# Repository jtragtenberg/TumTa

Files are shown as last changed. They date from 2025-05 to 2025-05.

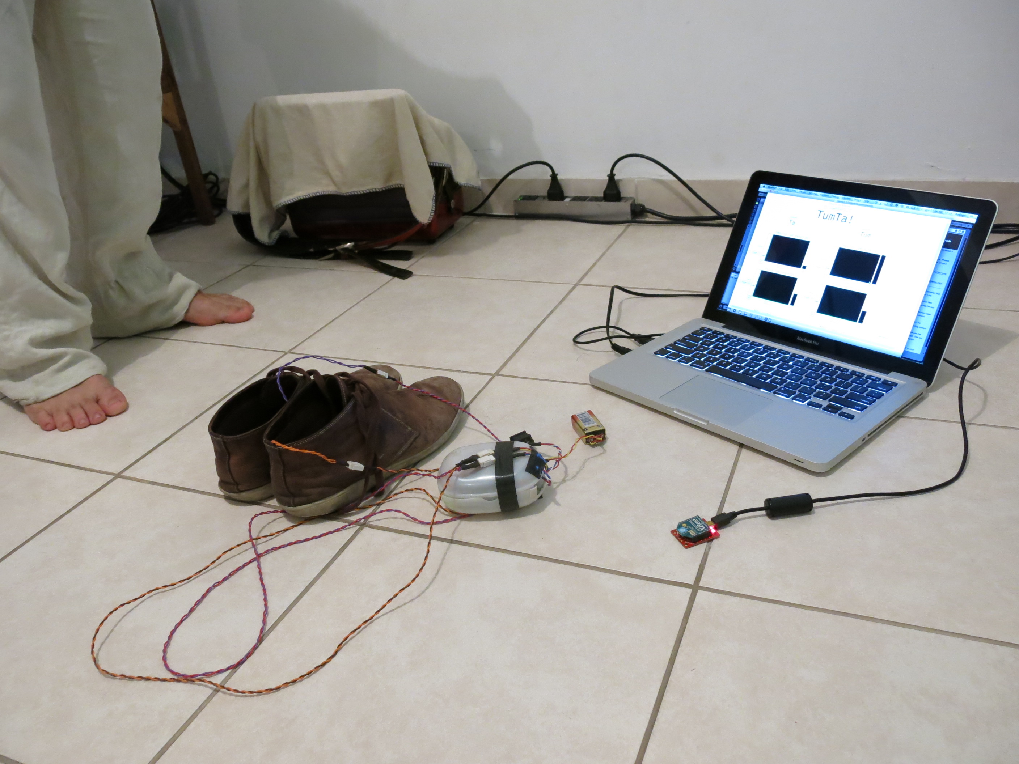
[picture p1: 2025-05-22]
Imagens/IMG_2408.JPG

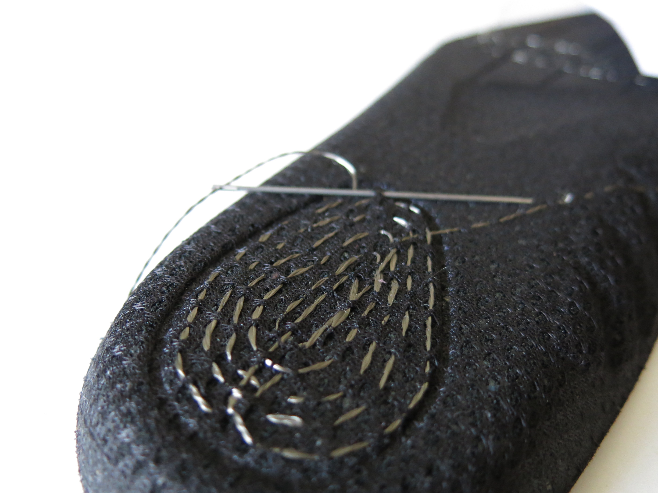
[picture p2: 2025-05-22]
Imagens/IMG_2268.JPG

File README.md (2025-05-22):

# TumTa - Instrumento Digital de Dança e Música voltado a disparar samples sonoros a partir de pisadas através de uma palmilha sensível à pressão (FSR).

## Descrição

**TumTa** é um sistema híbrido, modular e open-source, que integra:

- Hardware de detecção percussiva sensível ao toque.
- Firmware embarcado com processamento em tempo real.
- Comunicação sem fio via **XBee**.
- Software receptor/visualizador desenvolvido em **C++ com OpenFrameworks**.

O sistema foi desenvolvido para aplicações em:

- Performance musical ao vivo.
- Instalações audiovisuais interativas.
- Pesquisas em interfaces físico-digitais.

## Componentes do Projeto

### 1. Circuito eletrônico

- Projeto de circuito com sensores piezoelétricos.
- Arquivos disponíveis no repositório:
  - Esquema elétrico (.sch).
  - PCB para fabricação ou CNC (.brd).
  - Layout da caixa para **corte a laser** (.svg ou .dxf).

Todos os arquivos estão na pasta `hardware/`.

### 2. Firmware (Arduino)

- Processamento de sinais em tempo real com:
  - Derivada via diferenças finitas (float).
  - Controle **não bloqueante** com `millis()`.
  - Sistema de **debounce** ajustável.
  - Modos de envio: `DEBUG` e `LIVE`.

- Comunicação serial com módulo **XBee** para transmissão sem fio.
- Código modular e otimizado disponível na pasta `firmware/`.

### 3. Comunicação sem fio (XBee)

- Configuração clássica:
  - Transmissor: Arduino + XBee.
  - Receptor: XBee + computador.

- Baudrate: 38400.
- Comunicação robusta com protocolo de mensagem e **checksum**.

### 4. Software receptor (OpenFrameworks)

Desenvolvido em **C++ com OpenFrameworks**, o software realiza:

- Recepção e interpretação das mensagens enviadas via XBee.
- Detecção de picos ajustável, permitindo o controle da sensibilidade à intensidade.
- Mapeamento dinâmico: a intensidade controla diretamente a dinâmica dos samples gerados.
- Contorno de ruídos: filtros e thresholds ajustáveis para minimizar falsos disparos.
- Interface com `ofxGui` para ajuste em tempo real.
- Visualização gráfica dos dados recebidos.

**Integração MIDI**:

- O software converte os eventos de detecção percussiva em **mensagens MIDI**.
- Utiliza bibliotecas como `ofxMidi` para envio MIDI.
- As mensagens MIDI são enviadas em tempo real para uma **DAW** (ex.: **Ableton Live**, **Logic Pro**, **Reaper**).
- Cada batida detectada pode ser mapeada para **notas MIDI específicas**, disparando samples ou instrumentos virtuais.

## Fluxo geral do sistema

```
Sensor Piezo → Arduino → Processamento → XBee TX → ~~~ Wireless ~~~ → XBee RX → OpenFrameworks → MIDI OUT → DAW (Ableton Live)
```

## Arquivos incluídos no repositório

| Pasta | Conteúdo |
|---|---|
| `PCB/ Enclosure/ | Esquema, PCB (.brd/.sch), layout da caixa (.svg/.dxf). |
| `Arduino/` | Código Arduino (`TumTa.ino`). |
| `OpenFrameWorks/`| Projeto OpenFrameworks com envio MIDI. |
| `Imagens/` | Fotos |
| `Max/` | Software Aternativo |

## Como montar o sistema

### 1. Hardware

- Construa o circuito com base no esquema elétrico.
- Corte a caixa com laser utilizando os arquivos vetoriais.
- Monte os componentes, conecte sensores, potenciômetro e switches.

### 2. Firmware

- Abra o `TumTa.ino` no Arduino IDE.
- Compile e envie para a placa Arduino.

### 3. Comunicação

- Configure os módulos **XBee**:
  - Mesma PAN ID.
  - Baudrate: 38400.
- Conecte o transmissor ao Arduino e o receptor ao computador.

### 4. Software

- Instale **OpenFrameworks** (versão 0.11 ou superior).
- Inclua `ofxMidi` para envio de mensagens MIDI.
- Abra o projeto `TumTa` na pasta `software/`.
- Ajuste:
  - Porta serial para XBee receptor.
  - Configurações MIDI (porta virtual ou física).
- Compile e execute.
- Configure a DAW (ex.: **Ableton Live**) para receber as mensagens MIDI provenientes do software.

## Parâmetros ajustáveis

| Parâmetro | Local | Valor padrão |
|--- |--- |--- |
| Threshold | Potenciômetro (A7) | Variável |
| Debounce Time | Estrutura `ChannelState` | 150 ms |
| Process Interval | Global | 1 ms |
| Tempo de Pisca (LED) | Global | 500 ms |
| Sensibilidade de Pico | Interface do OpenFrameworks | Ajustável |
| Dinâmica de Sample/MIDI  | Mapeamento no software | Ajustável |
| Notas MIDI mapeadas | Configuração no OpenFrameworks | Ajustável |

## Diferenciais do projeto

- Modular e expansível, com suporte para múltiplos sensores.
- Processamento híbrido, com divisão de carga entre hardware e software.
- Integração robusta com sistemas artísticos interativos e musicais.
- Arquivos completos: circuito, caixa e software.
- Envio de MIDI para **DAW** em tempo real.

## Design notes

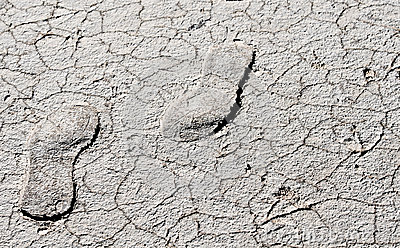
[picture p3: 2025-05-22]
Enclosure/texturas/pegadas-em-uma-terra-rachada-seca-25556899.jpg

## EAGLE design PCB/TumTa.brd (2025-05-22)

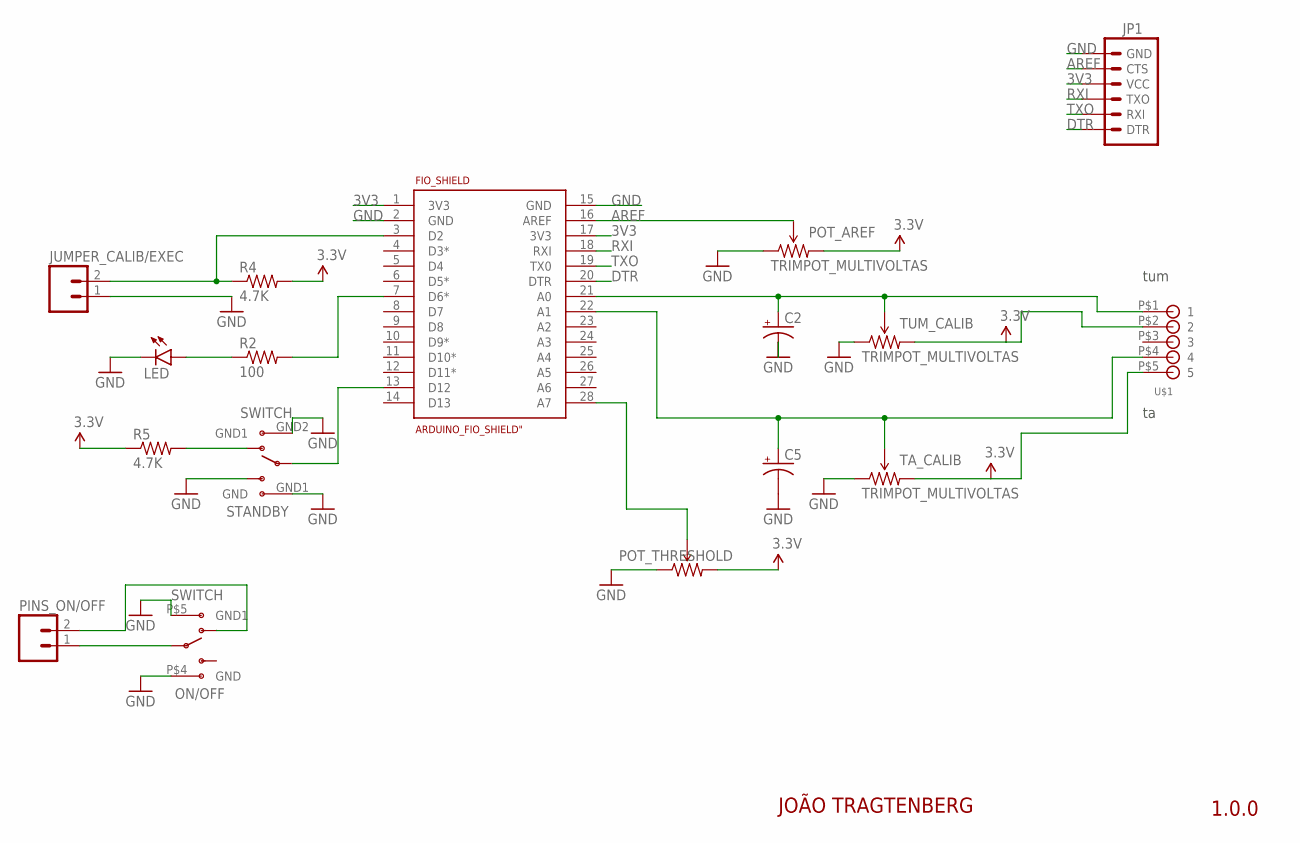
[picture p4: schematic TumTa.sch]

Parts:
C2, C5: CAP_POLPTH2; CPOL-RADIAL-10UF-25V
FIO_SHIELD: ARDUINO_FIO_SHIELD"; ARDUINO_FIO_SHIELD
JP1: ARDUINO_SERIAL_PROGRAMPTH; 1X06
JUMPER_CALIB/EXEC: M02PTH; 1X02
LED: LED-GREEN5MM_THRU; LED5MM
ON/OFF: SWITCH; SWITCH_HH_2POS_3PIN
PINS_ON/OFF: M02PTH; 1X02
POT_AREF: TRIMPOT_MULTIVOLTAS
POT_THRESHOLD: TRIMPOTBR; TRIM_POT_BR
R2: 100; 0603-RES
R4, R5: 4.7K; 0603-RES
STANDBY: SWITCH; SWITCH_HH_2POS_6PIN
TA_CALIB: TRIMPOT_MULTIVOLTAS
TUM_CALIB: TRIMPOT_MULTIVOLTAS
U$1: SCREWTERMINAL-5; SCREWTERMINAL-0.1"-5_BR

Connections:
3V3: FIO_SHIELD.1 (3V3), FIO_SHIELD.17 (3V3), JP1.4 (VCC), POT_AREF.3 (CW), POT_THRESHOLD.3 (CW), R4.2, R5.1, TA_CALIB.3 (CW), TUM_CALIB.3 (CW), U$1.P$2 (2), U$1.P$5 (5)
A0: C2.1 (+), FIO_SHIELD.21 (A0), TUM_CALIB.2 (WIPER), U$1.P$1 (1)
A1: C5.1 (+), FIO_SHIELD.22 (A1), TA_CALIB.2 (WIPER), U$1.P$4 (4)
AREF: FIO_SHIELD.16 (AREF), JP1.5 (CTS), POT_AREF.2 (WIPER)
D10: FIO_SHIELD.7 (D6*), R2.2
DTR: FIO_SHIELD.20 (DTR), JP1.1 (DTR)
GND: C2.2 (-), C5.2 (-), FIO_SHIELD.2 (GND), FIO_SHIELD.15 (GND), JP1.6 (GND), JUMPER_CALIB/EXEC.1, LED.K (C), ON/OFF.P$4 (GND), ON/OFF.P$5 (GND1), POT_AREF.1 (CCW), POT_THRESHOLD.1 (CCW), STANDBY.GND1 (GND), STANDBY.GND2 (GND1), STANDBY.P3A (S), TA_CALIB.1 (CCW), TUM_CALIB.1 (CCW)
unnamed: FIO_SHIELD.28 (A7), POT_THRESHOLD.2 (WIPER)
unnamed: FIO_SHIELD.3 (D2), JUMPER_CALIB/EXEC.2, R4.1
unnamed: FIO_SHIELD.13 (D12), STANDBY.P2A
unnamed: R5.2, STANDBY.P1A (O)
unnamed: ON/OFF.P$1 (O), PINS_ON/OFF.2
unnamed: LED.A, R2.1
unnamed: ON/OFF.P$2, PINS_ON/OFF.1
RXI: FIO_SHIELD.18 (RXI), JP1.3 (TXO)
TXO: FIO_SHIELD.19 (TX0), JP1.2 (RXI)

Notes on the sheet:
JOÃO TRAGTENBERG
1.0.0
tum

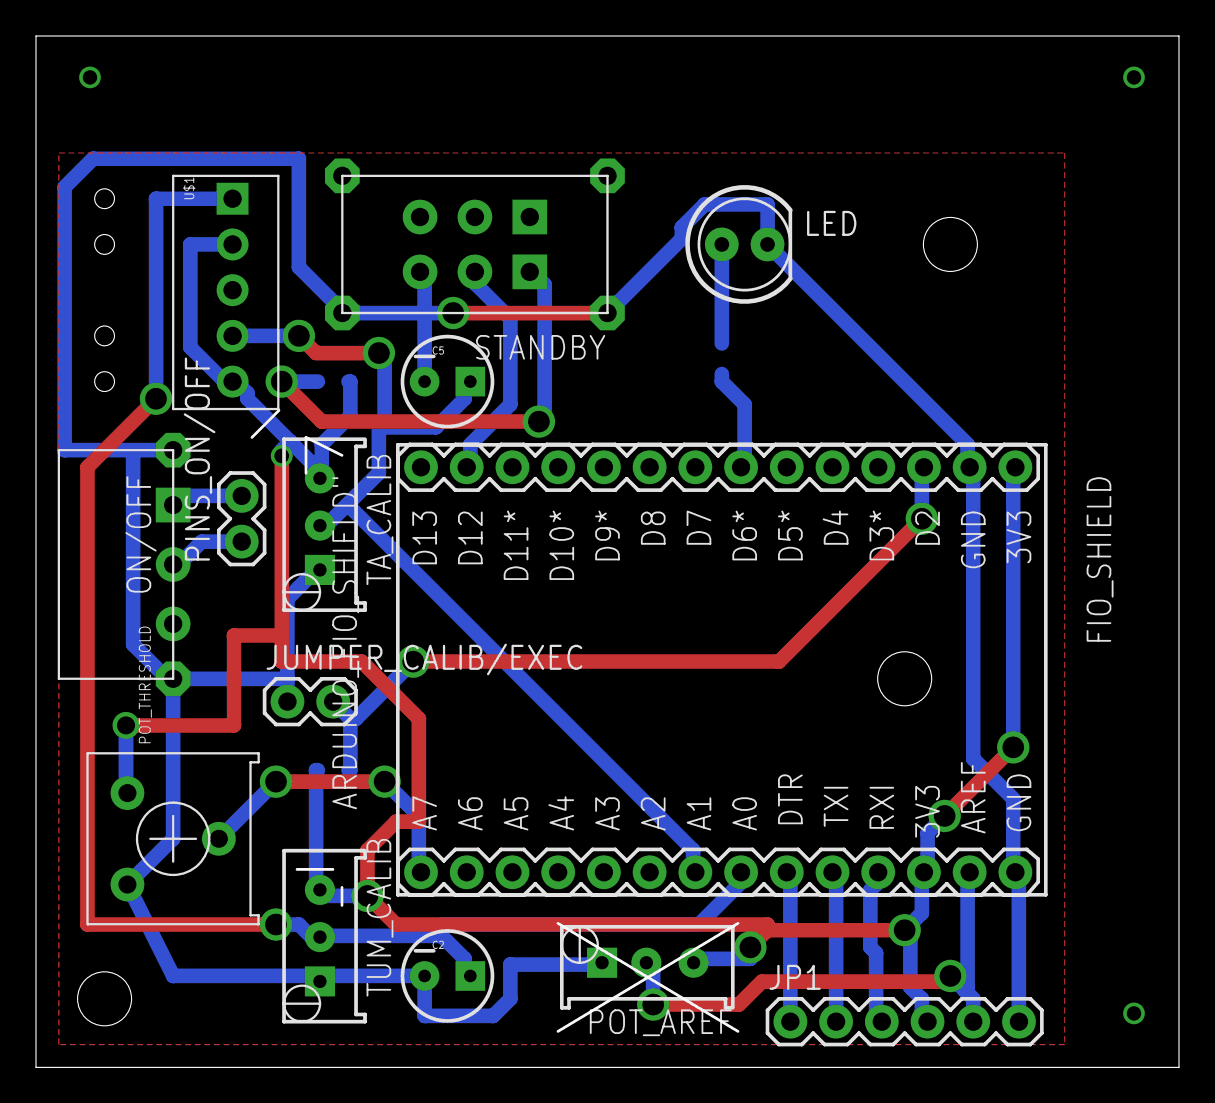
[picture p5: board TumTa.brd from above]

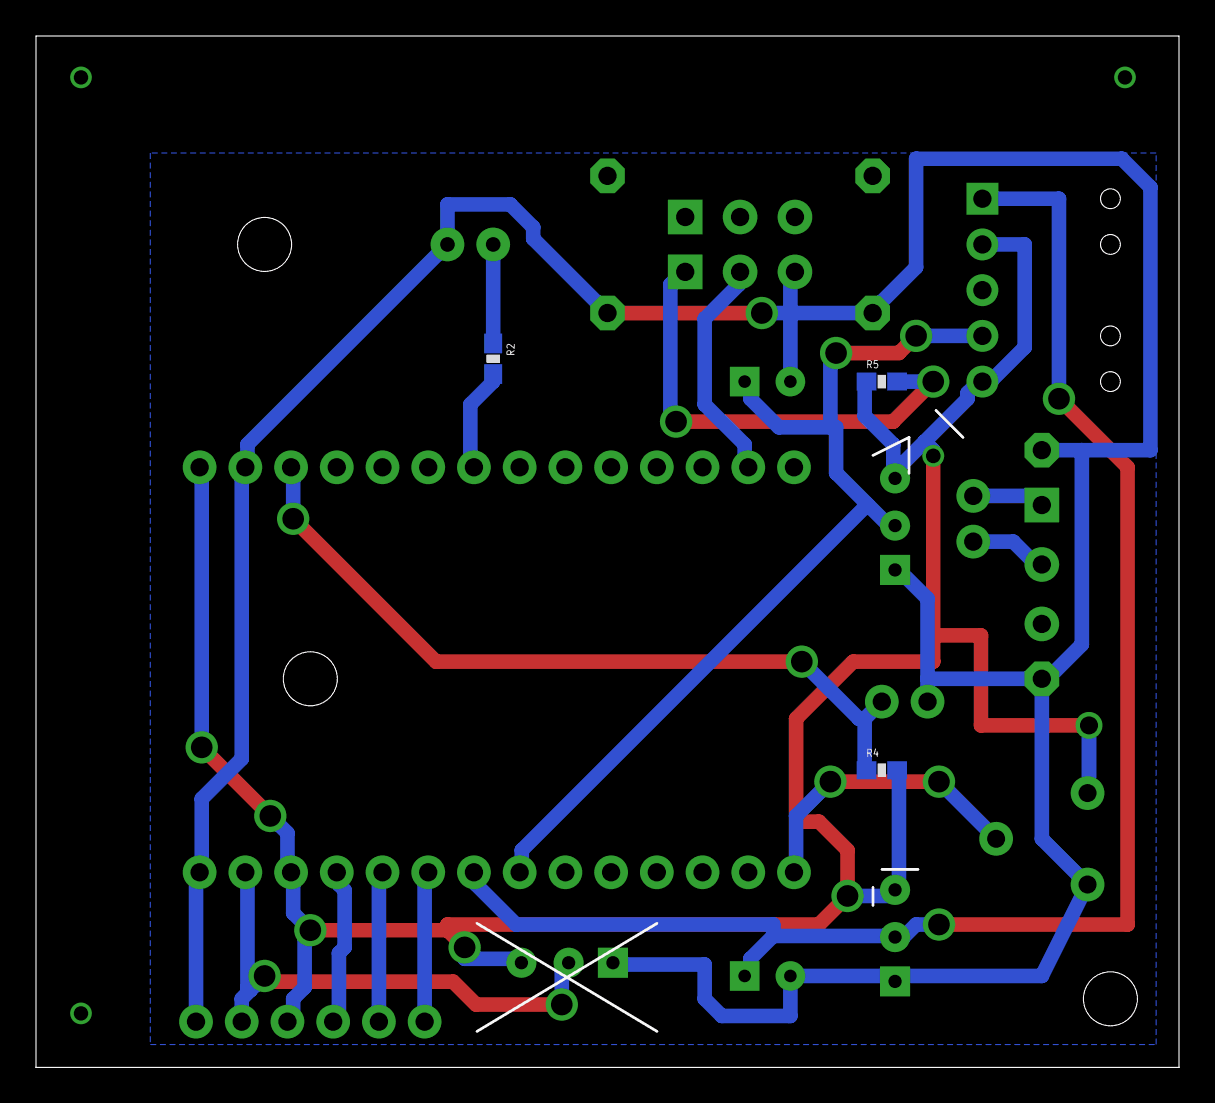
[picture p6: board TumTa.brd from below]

Board: 2 copper layers, 63.5 x 57.3 mm, 17 parts (3 on the bottom side), 16 nets.

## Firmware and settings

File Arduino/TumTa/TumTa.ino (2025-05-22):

// ---- Configurações de pinos ----
#define TUM_PIN A0
#define TUM_CHANNEL 0
#define TA_PIN A1
#define TA_CHANNEL 1
#define MODE_SWITCH_PIN 2
#define THRESHOLD_PIN A7
#define STANDBY_SWITCH_PIN 12
#define LED_PIN 6

// ---- Parâmetros gerais ----
const int numReadings = 5;
int threshold = 20;

const unsigned long processInterval = 1; // intervalo mínimo entre processamentos (ms)
unsigned long lastProcessTime = 0;

typedef struct {
  int debounceTime = 150;
  int derivative = 0;
  int intensity = 0;
  int maxDerivative = 0;
  bool debouncing = false;
  unsigned long lastDebounceTime = 0;
  bool waitingForPeak = true;
  int derivativeWindow[5] = {0};
} ChannelState;

ChannelState channels[2];

// ---- Mensagens ----
byte debugMessage[15];
byte liveMessage[7];

// ---- Variáveis globais ----
bool isDebugging = false;
bool standby = false;
unsigned long tempoStandby = 0;
const int tempoBlink = 500;
bool blinkFlag = false;

// ---- Funções auxiliares ----
float getDerivative(ChannelState *ch, int value) {
  for (int i = 4; i > 0; i--) {
    ch->derivativeWindow[i] = ch->derivativeWindow[i - 1];
  }
  ch->derivativeWindow[0] = value;

  float derivative = 2.08 * ch->derivativeWindow[0] 
                   - 4.0 * ch->derivativeWindow[1] 
                   + 3.0 * ch->derivativeWindow[2] 
                   - 1.33 * ch->derivativeWindow[3] 
                   + 0.25 * ch->derivativeWindow[4];

  return derivative;
}

int computeIntensity(ChannelState *ch, int newDerivative, int threshold) {
  unsigned long now = millis();

  if (!ch->debouncing && newDerivative > threshold) {
    ch->lastDebounceTime = now;
    ch->debouncing = true;
  }

  if ((now - ch->lastDebounceTime) > ch->debounceTime) {
    ch->debouncing = false;
    ch->intensity = 0;
    ch->waitingForPeak = true;
    ch->maxDerivative = 0;
    digitalWrite(LED_PIN, LOW);
  }

  if (ch->debouncing && ch->waitingForPeak) {
    if (newDerivative > ch->maxDerivative) {
      ch->maxDerivative = newDerivative;
    } else {
      ch->intensity = ch->maxDerivative;
      ch->waitingForPeak = false;
      digitalWrite(LED_PIN, HIGH);
      Serial.write(ch->intensity / 10);
    }
  }
  return ch->intensity;
}

void setDebugMessage(int tumPressure, int taPressure, int tumDerivative, int taDerivative, int tumIntensity, int taIntensity) {
  debugMessage[0] = 0xFF;
  debugMessage[1] = 0xFF;
  debugMessage[2] = lowByte(tumPressure);
  debugMessage[3] = highByte(tumPressure);
  debugMessage[4] = lowByte(taPressure);
  debugMessage[5] = highByte(taPressure);
  debugMessage[6] = lowByte(tumDerivative);
  debugMessage[7] = highByte(tumDerivative);
  debugMessage[8] = lowByte(taDerivative);
  debugMessage[9] = highByte(taDerivative);
  debugMessage[10] = lowByte(tumIntensity);
  debugMessage[11] = highByte(tumIntensity);
  debugMessage[12] = lowByte(taIntensity);
  debugMessage[13] = highByte(taIntensity);

  debugMessage[14] = 0;
  for (int i = 2; i < 14; i++) {
    debugMessage[14] += debugMessage[i];
  }

  Serial.write(debugMessage, sizeof(debugMessage));
}

void setLiveMessage(int tumIntensity, int taIntensity) {
  liveMessage[0] = 0xFE;
  liveMessage[1] = 0xFE;
  liveMessage[2] = lowByte(tumIntensity);
  liveMessage[3] = highByte(tumIntensity);
  liveMessage[4] = lowByte(taIntensity);
  liveMessage[5] = highByte(taIntensity);

  liveMessage[6] = 0;
  for (int i = 2; i < 6; i++) {
    liveMessage[6] += liveMessage[i];
  }

  Serial.write(liveMessage, sizeof(liveMessage));
}

// ---- Setup ----
void setup() {
  Serial.begin(38400);

  pinMode(TUM_PIN, INPUT);
  pinMode(TA_PIN, INPUT);
  pinMode(MODE_SWITCH_PIN, INPUT);
  pinMode(THRESHOLD_PIN, INPUT);
  pinMode(STANDBY_SWITCH_PIN, INPUT);
  pinMode(LED_PIN, OUTPUT);
}

// ---- Loop ----
void loop() {
  unsigned long now = millis();

  standby = digitalRead(STANDBY_SWITCH_PIN);
  threshold = analogRead(THRESHOLD_PIN);

  if (standby) {
    if (now - tempoStandby > tempoBlink) {
      digitalWrite(LED_PIN, blinkFlag ? LOW : HIGH);
      tempoStandby = now;
      blinkFlag = !blinkFlag;
    }
  } else {
    if (now - lastProcessTime >= processInterval) {
      lastProcessTime = now;

      isDebugging = digitalRead(MODE_SWITCH_PIN);

      int tumValue = analogRead(TUM_PIN);
      int taValue = analogRead(TA_PIN);

      float tumDerivative = getDerivative(&channels[TUM_CHANNEL], tumValue);
      float taDerivative = getDerivative(&channels[TA_CHANNEL], taValue);

      int tumIntensity = computeIntensity(&channels[TUM_CHANNEL], tumDerivative, threshold);
      int taIntensity = computeIntensity(&channels[TA_CHANNEL], taDerivative, threshold);

      if (isDebugging) {
        setDebugMessage(tumValue, taValue, (int)tumDerivative, (int)taDerivative, tumIntensity, taIntensity);
      } else {
        setLiveMessage(tumIntensity, taIntensity);
      }
    }
  }
}

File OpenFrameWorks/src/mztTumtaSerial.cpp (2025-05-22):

#include "mztTumtaSerial.h"

void mztTumtaSerial::setup()
{

	
	iniSerial(0);
	isPackageReady = false;
	contPackage = 0;
	serialActive = true;
	iniGui();
}

void mztTumtaSerial::update()
{
	checkGuiSerialDeviceName();
}

void mztTumtaSerial::updateSerialValues()
{
	if(paramSerialOn)
	{
		emptyValues();
		int serialRead;
		while((serialRead = serial.readByte()) >= 0)
		{
			checkByteAndUpdateVectors(serialRead);
		}
	}
}

void mztTumtaSerial::checkByteAndUpdateVectors(int value)
{
	setPackage(value);
	
	if(isPackageReady)
	{
		if(debugMessage)
		{
			// TUM
			tum.pressure.push_back(package[0] + (package[1] * 255));
			tum.derivative.push_back(package[4] + (package[5] * 255));
			tum.intensity.push_back(package[8] + (package[9] * 255));
			// TA
			ta.pressure.push_back(package[2] + (package[3] * 255));
			ta.derivative.push_back(package[6] + (package[7] * 255));
			ta.intensity.push_back(package[10] + (package[11] * 255));
		}
		else
		{
			// TUM
			tum.pressure.push_back(0);
			tum.derivative.push_back(0);
			tum.intensity.push_back(package[0] + (package[1] * 255));
			// TA
			ta.pressure.push_back(0);
			ta.derivative.push_back(0);
			ta.intensity.push_back(package[2] + (package[3] * 255));
		}
	}
}

void mztTumtaSerial::close()
{
	serial.close();
}

// GETTERS
vector<int> mztTumtaSerial::getTumPressure()
{
	return tum.pressure;
}

vector<int> mztTumtaSerial::getTumDerivative()
{
	return tum.derivative;
}

vector<int> mztTumtaSerial::getTumIntensity()
{
	return tum.intensity;
}

vector<int> mztTumtaSerial::getTaPressure()
{
	return ta.pressure;
}

vector<int> mztTumtaSerial::getTaDerivative()
{
	return ta.derivative;
}

vector<int> mztTumtaSerial::getTaIntensity()
{
	return ta.intensity;
}

void mztTumtaSerial::setPackage(int newChar)
{
	switch (contPackage)
	{
		case 0:
			isPackageReady = false;
			if(newChar == 255)
			{
				contPackage++;
				debugMessage = true;
			}
			else if(newChar == 254)
			{
				contPackage++;
				debugMessage = false;
			}
			else
			{
				contPackage = 0;
			}
			break;
		case 1:
			if(newChar == 255 && debugMessage)
			{
				contPackage++;
				debugMessage = true;
			}
			else if(newChar == 254 && !debugMessage)
			{
				contPackage++;
				debugMessage = false;
			}
			else
			{
				contPackage = 0;
				debugMessage = false;
			}
			break;
		case 2:
			package[0] = newChar;  // [0] Pressure Tum DataLow or [0] Intensity Tum DataLow
			contPackage++;
			break;
		case 3:
			package[1] = newChar; // [1] Pressure Tum DataHigh or [1] Intensity Tum DataHigh
			contPackage++;
			break;
		case 4:
			package[2] = newChar; // [2] Pressure Ta DataLow or [2] Intensity Ta DataLow
			contPackage++;
			break;
		case 5:
			package[3] = newChar; // [3] Pressure Ta DataHigh or [3] Intensity Ta DataLow
			contPackage++;
			break;
		case 6:
			if(!debugMessage)
			{
				packageChecksum = newChar; // Live Message Checksum
				unsigned char localChecksum = 0;
				for(int i = 0; i < 4; i++)
				{
					localChecksum += package[i];
				}
				if(packageChecksum == localChecksum)
				{
					isPackageReady = true;
				}
				contPackage = 0;
			}
			else
			{
				package[4] = newChar; // [4] Derivative Tum DataLow
				contPackage++;
			}
			break;
		case 7:
			package[5] = newChar; // [5] Derivative Tum DataHigh
			contPackage++;
			break;
		case 8:
			package[6] = newChar; // [6] Derivative Ta DataLow
			contPackage++;
			break;
		case 9:
			package[7] = newChar; // [7] Derivative Ta DataHigh
			contPackage++;
			break;
		case 10:
			package[8] = newChar; // [8] Intensity Tum DataLow
			contPackage++;
			break;
		case 11:
			package[9] = newChar; // [9] Intensity Tum DataHigh
			contPackage++;
			break;
		case 12:
			package[10] = newChar; // [10] Intensity Ta DataLow
			contPackage++;
			break;
		case 13:
			package[11] = newChar; // [11] Intensity Ta DataHigh
			contPackage++;
			break;
		case 14:
			packageChecksum = newChar; // Debug Message Checksum
			unsigned char localDebuggingChecksum = 0;
			for(int i = 0; i < 12; i++)
			{
				localDebuggingChecksum += package[i];
			}
			if(packageChecksum == localDebuggingChecksum)
			{
				isPackageReady = true;
			}
			contPackage = 0;
			break;
	}
}

void mztTumtaSerial::emptyValues()
{
	// TUM
	tum.pressure.clear();
	tum.derivative.clear();
	tum.intensity.clear();
	// TA
	ta.pressure.clear();
	ta.derivative.clear();
	ta.intensity.clear();
}

// SERIAL
void mztTumtaSerial::iniSerial(int serialDeviceId = 0)
{
	if(serial.isInitialized())
	{
		serial.close();
	}
	serial.setup(serialDeviceId, SERIAL_BAUDS);
	paramSerialDeviceNameSelected = serialDeviceId;
	serial.flush();
}

void mztTumtaSerial::setGuiSerialDeviceName()
{
	paramSerialDeviceName.empty();
	vector<ofSerialDeviceInfo> serialDeviceList = serial.getDeviceList();
	for(int i = 0; i < serialDeviceList.size(); i++)
	{
		ofParameter<bool> serialDevice;
		serialDevice.set(serialDeviceList[i].getDeviceName(), false);
		paramSerialDeviceName.push_back(serialDevice);
	}
}

void mztTumtaSerial::checkGuiSerialDeviceName()
{
	paramSerialDeviceName[paramSerialDeviceNameSelected] = true;
	for(int i = 0; i < paramSerialDeviceName.size(); i++)
	{
		if(paramSerialDeviceName[i] && paramSerialDeviceNameSelected != i)
		{
			paramSerialDeviceName[paramSerialDeviceNameSelected] = false;
			paramSerialDeviceNameSelected = i;
			paramSerialDeviceName[i] = true;
			iniSerial(paramSerialDeviceNameSelected);
		}
	}
}

// GUI
void mztTumtaSerial::iniGui()
{
	parameters.setName("Serial");
	parameters.add(paramSerialOn.set("Active", true));
	// Serial Port Names
	parameterGroupSerialPort.setName("Serial Ports");
	setGuiSerialDeviceName();
	for(int i = 0; i < paramSerialDeviceName.size(); i++)
	{
		parameterGroupSerialPort.add(paramSerialDeviceName[i]);
		if(i == paramSerialDeviceNameSelected)
		{
			paramSerialDeviceName[paramSerialDeviceNameSelected] = true;
		}
	}
	parameters.add(parameterGroupSerialPort);
}

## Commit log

2025-05-22 circuito v0_2_3
    [TumTa.brd, TumTa.sch]
2025-05-22 added samples, live, openframeworks
    [Project8_1.cfg]
2025-05-22 added pcb image
2025-05-22 added abelton live sessions
    [Project8_1.cfg]
2025-05-22 corrigi nome de arquivo
    [TumTa.ino]
2025-05-22 voltei duas versões
2025-05-22 mudança de delayMicrroseconds para non blocking strategy

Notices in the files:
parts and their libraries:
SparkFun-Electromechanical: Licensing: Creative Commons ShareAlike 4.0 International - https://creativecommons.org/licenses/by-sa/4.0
